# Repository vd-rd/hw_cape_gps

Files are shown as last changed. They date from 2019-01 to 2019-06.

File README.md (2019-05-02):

## Overview
Designed for accurate positioning inside embedded projects, this GPS cape offers extended telemetry information, as well as multiple choices for antenna type and placing as well as SoC options.
 The module is designed to accept either:
  - Fibocom GTS-4E-60 (tested)
  - Simcom SIM-28
  - uBlox Neo-M6/7/8
 Regarding connectivity options, the module can be equipped with either an active or passive antenna, connected via a standard u.Fl connector or placed on the carrier PCB.
Detailed information about positioning capabilities of the module can be found in the [GPS](/doc/gps.md) page.

### Project notes
Current development is on the master branch. Earlier revisions have been moved on the archive branch.

### Resources
You can find all necesary information to build or evaluate the module here:
   - [View 3D board render](https://a360.co/2DnqBSM)
   - [Fabrication files](https://github.com/vd-rd/hw_cape_gps/releases)
 
## Features
 - Low power consumption (<30mA)
 - Board can be placed in a true shutdown state (<20uA)
 - Extended temperature range of operation (-40C - 85)
 Detailed information about technical capabilities of the module can be found in the [hardware description](/docs/hardware.md) page.

## Telemetry data
 The module is able to provide standard NMEA sentences on a UART interface. Supported sentences:
 - $GPGGA - Time, position and fix type data
 - $GPGSA - GPS receiver operating mode, satellites used in the position solution, and DOP values
 - $GPGSV - Number of GPS satellites in view satellite ID numbers, elevation, azimuth, & SNR values
 - $GPRMC - Time, date, position, course and speed data
Detailed information about the sentences and parameters can be found in [telemetry](/docs/telemetry.md) page.

## Production
 The module is designed on a 40x40mm double layer PCB, with components placed on a single side for easy assembly.
 The total height of the module (without connectors mounted) is 3mm without the passive antenna mounted and 10mm otherwise.
 Detailed information about the stack-up, BOM and configuration options can be found on the [manufacturing](/docs/manufacturing.md) page.

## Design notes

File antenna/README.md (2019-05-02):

### GPS module antenna
GPS antennas fall into two main categories
 * passive 
 * active
Main differences and advantages are discussed below

### Passive antenna
TBD
### Active antenna
TBD

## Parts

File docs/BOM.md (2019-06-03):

## Revision 1.0 BOM

[Complete BOM and example parts]()

| Qty | Parts | Package | Value | Description | Part id |
| --- | --- | --- |--- | --- | --- |

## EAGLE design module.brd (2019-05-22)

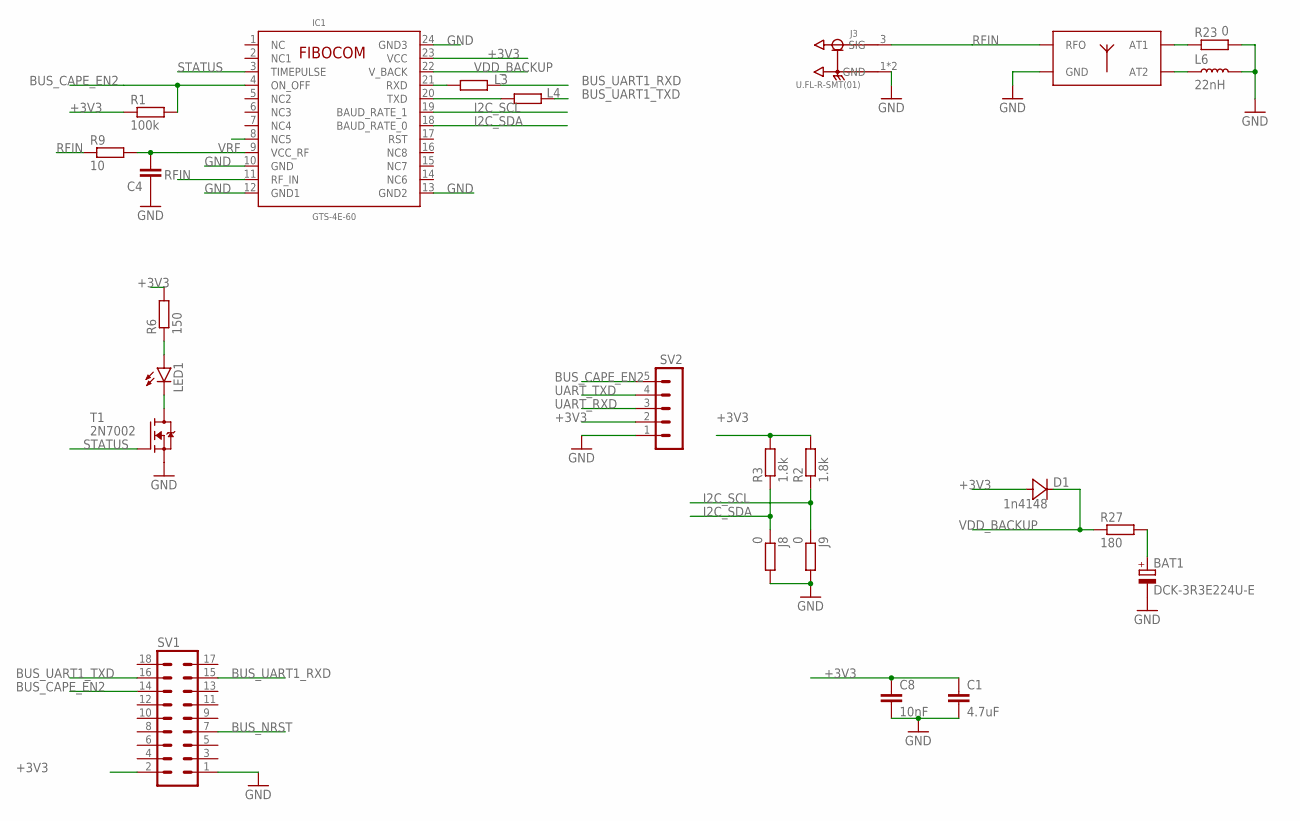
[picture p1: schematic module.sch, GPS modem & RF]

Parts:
ANT1: M20047; PCBCOMPONENT_1
BAT1: DCK-3R3E224U-E; 621
C1: 4.7uF; C0603
C4: 10nF; C0402K
C8: 10nF; C0603
D1: 1n4148; SOD323
IC1: GTS-4E-60; _GTS_4E_60
J3: U.FL-R-SMT(01); HRS_U.FL-R-SMT(01)
J8, J9: 0; R0603
L3, L4: blm15; R0603
L6: 22nH; L0402
LED1: LEDCHIP-LED0603; CHIP-LED0603
R1: 100k; R0603
R2, R3: 1.8k; R0603
R6: 150; R0603
R9: 10; R0402
R23: 0; R0402
R27: 180; R0603
SV1: MA09-2
SV2: MA05-1
T1: 2N7002; SOT95P240X110-3

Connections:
+3V3: C1.1, C8.1, D1.A, IC1.23 (VCC), R1.1, R2.2, R3.2, R6.2, SV1.2, SV2.2
BUS_CAPE_EN2: IC1.4 (ON_OFF), R1.2, SV1.14, SV2.5
BUS_NRST: SV1.7
BUS_UART1_RXD: L3.2, SV1.15
BUS_UART1_TXD: L4.2, SV1.16
GND: ANT1.2 (GND), ANT1.3 (GND), ANT1.4 (GND), BAT1.-, C1.2, C4.1, C8.2, IC1.10 (GND), IC1.12 (GND1), IC1.13 (GND2), IC1.24 (GND3), J3.1 (GND), J3.2 (GND), J8.2, J9.2, L6.2, R23.2, SV1.1, SV2.1, T1.2 (S)
I2C_SCL: IC1.19 (BAUD_RATE_1), J9.1, R2.1
I2C_SDA: IC1.18 (BAUD_RATE_0), J8.1, R3.1
unnamed: LED1.C, T1.3 (D)
unnamed: LED1.A, R6.1
unnamed: ANT1.1 (AT1), R23.1
unnamed: ANT1.6 (AT2), L6.1
unnamed: BAT1.+, R27.2
RFIN: ANT1.5 (RFO), IC1.11 (RF_IN), J3.3 (SIG), R9.1
STATUS: IC1.3 (TIMEPULSE), T1.1 (G)
UART_RXD: IC1.20 (TXD), L4.1, SV2.3
UART_TXD: IC1.21 (RXD), L3.1, SV2.4
VDD_BACKUP: D1.K (C), IC1.22 (V_BACK), R27.1
VRF: C4.2, IC1.9 (VCC_RF), R9.2

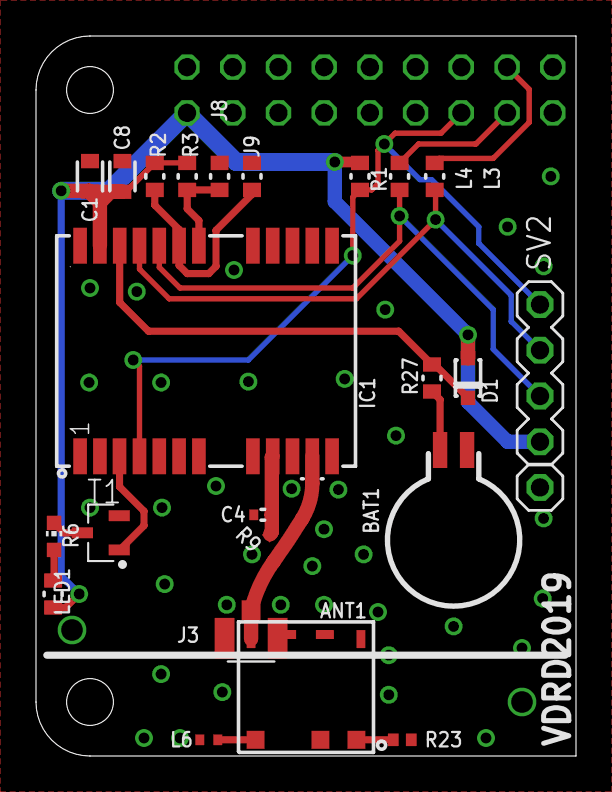
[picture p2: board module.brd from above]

Board: 2 copper layers, 30.0 x 40.0 mm, 24 parts (1 on the bottom side), 18 nets.

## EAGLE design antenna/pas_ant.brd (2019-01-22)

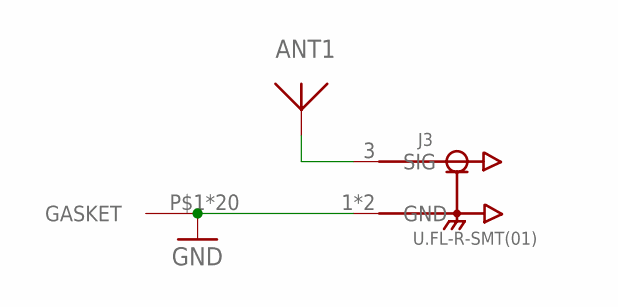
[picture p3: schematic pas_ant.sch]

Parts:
ANT1: ANT1590-2540A; 2540A
J3: U.FL-R-SMT(01); HRS_U.FL-R-SMT(01)
U$1: 2118718-2; 2118717-2

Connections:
GND2: J3.1 (GND), J3.2 (GND), U$1.P$1, U$1.P$2, U$1.P$3, U$1.P$4, U$1.P$5, U$1.P$6, U$1.P$7, U$1.P$8, U$1.P$9, U$1.P$10, U$1.P$11, U$1.P$12, U$1.P$13, U$1.P$14, U$1.P$15, U$1.P$16, U$1.P$17, U$1.P$18, U$1.P$19, U$1.P$20
unnamed: ANT1.P$1, J3.3 (SIG)

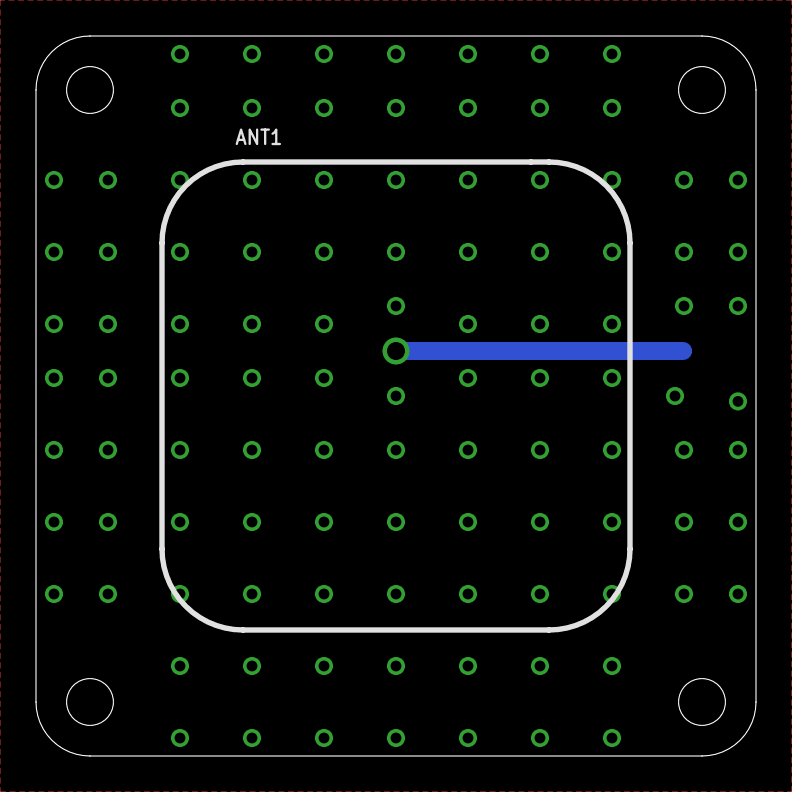
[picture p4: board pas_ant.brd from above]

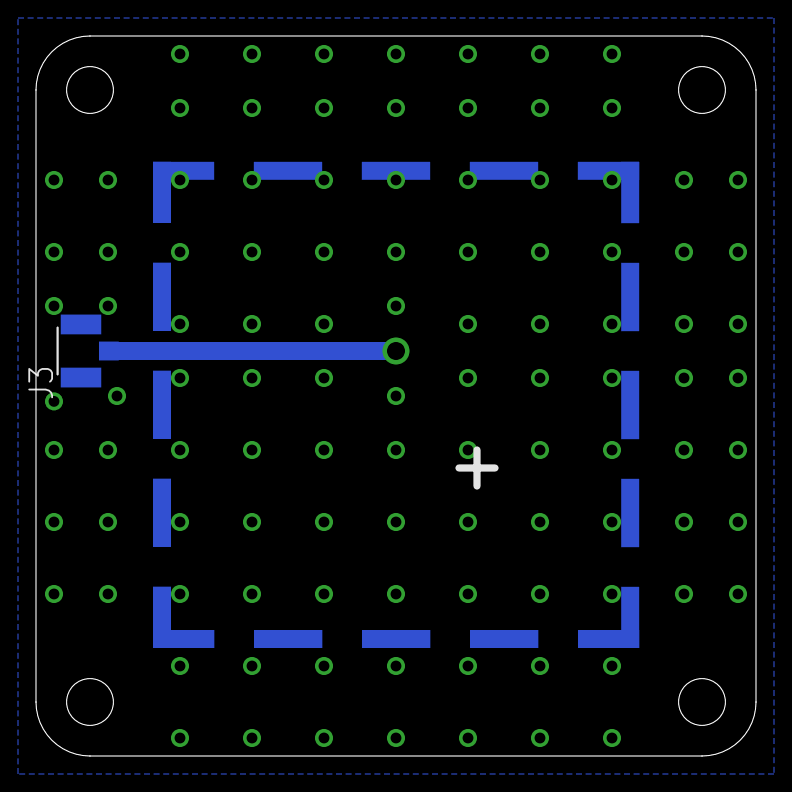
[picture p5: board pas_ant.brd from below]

Board: 2 copper layers, 40.0 x 40.0 mm, 3 parts (2 on the bottom side), 2 nets.

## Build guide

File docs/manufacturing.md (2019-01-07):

# Manufacturing information

## Module stack-up

## Module BOM

## Module files

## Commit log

2018-12-10 Upload New File
    [v0.1.0.sch]
2018-12-13 new board version
    [v0.3.0.brd, v0.3.0.sch]
2018-12-14 added eeprom, level shifter and routed traces
    [v0.3.0.brd, v0.3.0.sch]
2018-12-14 drc fixes
    [v0.3.0.brd, v0.3.0.sch]
2018-12-14 added values for parts
    [v0.3.0.brd, v0.3.0.sch]
2018-12-21 new revision, dropped usb, added load switch
    [v0.4.0.brd, v0.4.0.sch]
2019-01-01 pre release fixes
    [v0.4.0.brd, v0.4.0.sch]
2019-01-06 modified design according to bench findings
    [v0.4.0.brd, v0.4.0.sch]
2019-01-07 added assets and cleaned up
    [v0.5.0.brd, v0.5.0.sch, v0.5.1.brd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]
2019-01-07 cosmetic fixes
    [v0.5.1.brd, v0.5.1.sch]
2019-01-07 fixed values for components
    [v0.5.1.brd, v0.5.1.sch]
2019-01-07 added mfgr aiding
    [v0.5.1.brd]
2019-01-07 added usb connector
    [v0.6.0.brd, v0.6.0.sch]
2019-01-20 updated docs
    [v0.6.1.brd, v0.6.1.sch]
2019-01-20 Add board render
2019-01-22 added antennas
    [pas_ant.brd, pas_ant.sch, pas_ant_v1.0.0.brd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]
2019-01-23 added output files
    [pas_ant_v1.0.0.brd, v0.6.2.brd, v0.6.2.sch]
2019-03-12 space optimisation
    [v0.6.2.brd, v0.9.0.brd, v0.9.0.sch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]
2019-05-02 project: update structure
    [module.brd, module.sch, pas_ant.brd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]
2019-05-20 board: remove unused features
    [module.brd, module.sch]
2019-05-21 project: release v1.1.0 is finished
    [module.brd, module.sch]
2019-05-22 board: fixed connector error
    [module.brd]
2019-05-22 board: fixed legend for connector
    [module.brd]
